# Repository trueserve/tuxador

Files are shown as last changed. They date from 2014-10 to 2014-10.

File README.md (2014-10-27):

# Tuxador

A simple, secure door entry/open counter.

Still in the planning phase.

## Goals

- Make a basic, cost-effective counter
- Use an easy platform (this project will be used to teach)
- Support one doorway and a tamper switch, or two doorways
- Support proper security open/close/tamper/short loop
- Configurable ability to modify or reset the counter
- Indicate power on time, last tamper/short, last open
- All indications on inexpensive LCD display
- Directly mounts to common 16x2 character display or 1.8" Color LCD
- PCB design allows for destroying debugging interfaces
- 4-layer PCB, in cheap fab size, to bury any programming / debugging traces

## What is this useful for?

Some potential uses of this project include:

- Secure doors or closets with internal access logs
- Door entry audible alarm
- Generic upcounter for anything one might use one for

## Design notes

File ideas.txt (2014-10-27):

HW
==
- everything SMD so it can be epoxied or conformal coated easily
- put tamper stickers on external enclosure, probably more important
- ack button? screen light up button? some complex shit?
- ADC read of proper security loop to door contact
  this means: install proper loop resistors at door contact side
- enclosure has a tamper switch?
- internal tamper switch? can code for 2x doors, or 1x door and 1x tamper.
- Built in battery pack / charger? Probably on a separate 2-layer board.

SW
==
- beep/flash when door is opened?
- beeper and lcd backlight are both on external PWM
- LED indicator for something? maybe flash to show the unit is running?
- error display if reset from watchdog reset or BOD? only boot normally from POR?
  this info may be useful: http://www.avrfreaks.net/forum/determining-reset-source-atmega328p
- show state of various things
  - show overall powered uptime
  - show time since last open
  - show time since last tamper/short
  - show state (open/closed/tamper/short)
- Drive digital circuit outputs low to determine if inputs have been damaged
  - only do this occasionally, maybe once every couple of minutes, since it
    looks the same as a short to the system. however doing this is very fast,
    on the order of milliseconds, so it is worthwhile to do

IDEA
====
- maybe the front button can be a status/counter button to flip between the two screens,
  showing the counter normally, or the status

- maybe screen can stay flashing in severe alarm cases (tamper/short) until a timeout or
  cleared by getting into the device or something.

- two unused pins are I2C pins, so if you need I2C shit, those are your free pins.
  otherwise they can be unused, used as GPIO, etc.

====

julian:
you can see why off the shelf units may be ideal - less shit to think about, less code to write :)
if your time is worth nothing (or if you enjoy doing this / learning) then this will be cheaper,
otherwise it can be quite a bit more expensive

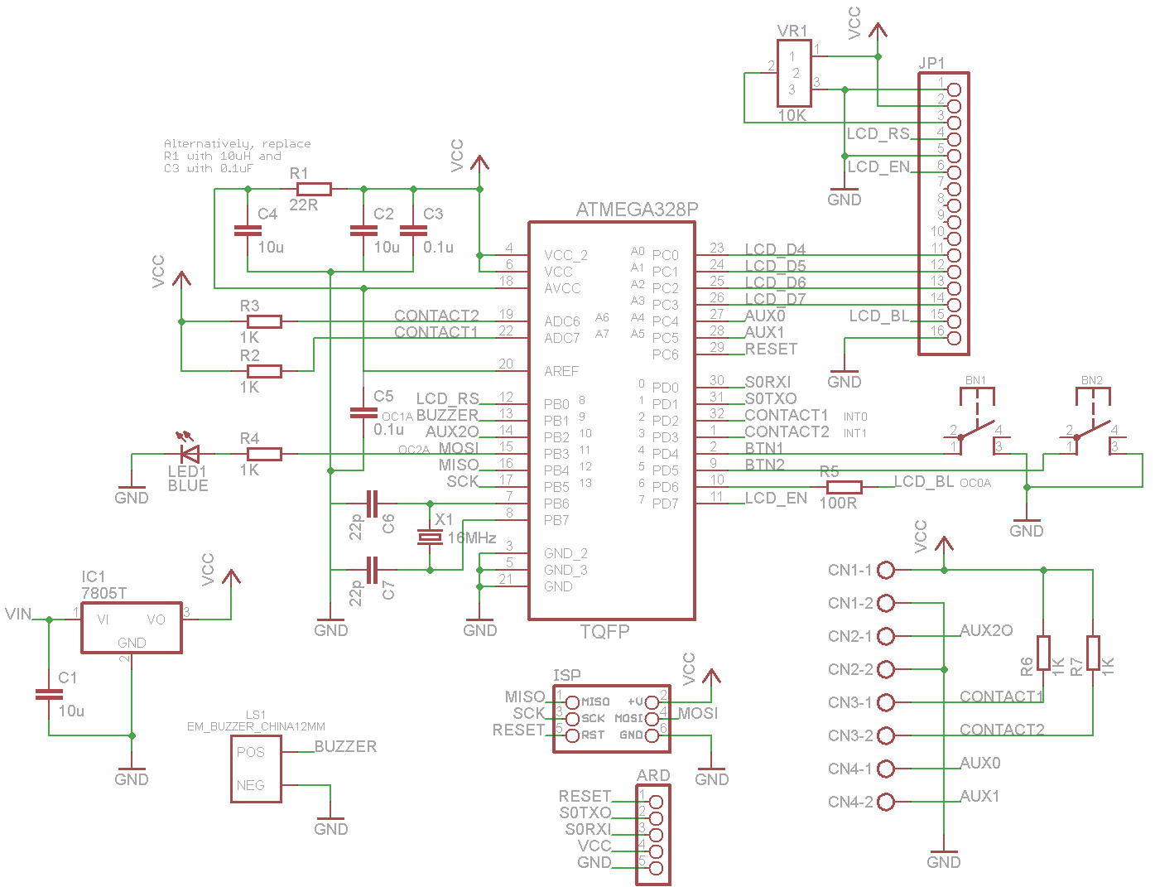
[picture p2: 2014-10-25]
misc/Tuxador_r1_sch_20141025.png

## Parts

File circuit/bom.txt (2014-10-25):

Prices are Qty 1 / Qty 10 for all count

1x 3.50/3.50 PCB
             Cost to manufacture ~$35 per 10 boards

1x 2.60/2.60 White-on-Blue 1602 LCD display
             ebay "1602 lcd" - lots of choices and price ranges, just need basic 5V version

1x 3.43/3.02 ATMega328P-AU or ATMega168PA-AU
             http://www.mouser.com/ProductDetail/Atmel/ATMEGA328P-AU/?qs=sGAEpiMZZMtVoztFdqDXO3RbBx7FKCmV
             I might have one on hand; not sure. 

1x 5.40/4.80 Hammond 1591ATBU case
             http://www.mouser.com/ProductDetail/Hammond-Manufacturing/1591ATBU/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

4x 2.00/0.35 Low-cost 5.08mm terminal connectors
             ebay "5.08mm terminal blue" as cheap as 10c each, usually packs of 20 or 100
             I have these on hand

1x ?.??/?.?? 6x6x6 4pin tact switch
             ebay "6x6 tact" - get whatever is cheapest. used for internal button
             I have these on hand

1x ?.??/?.?? 6x6x20mm 4pin tact switch
             ebay "6x6x20 tact" - used for front indicator button
             I have some ordered and coming in.

1x ?.??/?.?? tact button cap
             ebay "tact button cap round" - whatever style you want, for round buttons, should work OK
             they are hard to find, but I am sure we could mod the square ones to work - ignore for now

Totals
Qty 1:  $16.93
Qty 10: $14.27

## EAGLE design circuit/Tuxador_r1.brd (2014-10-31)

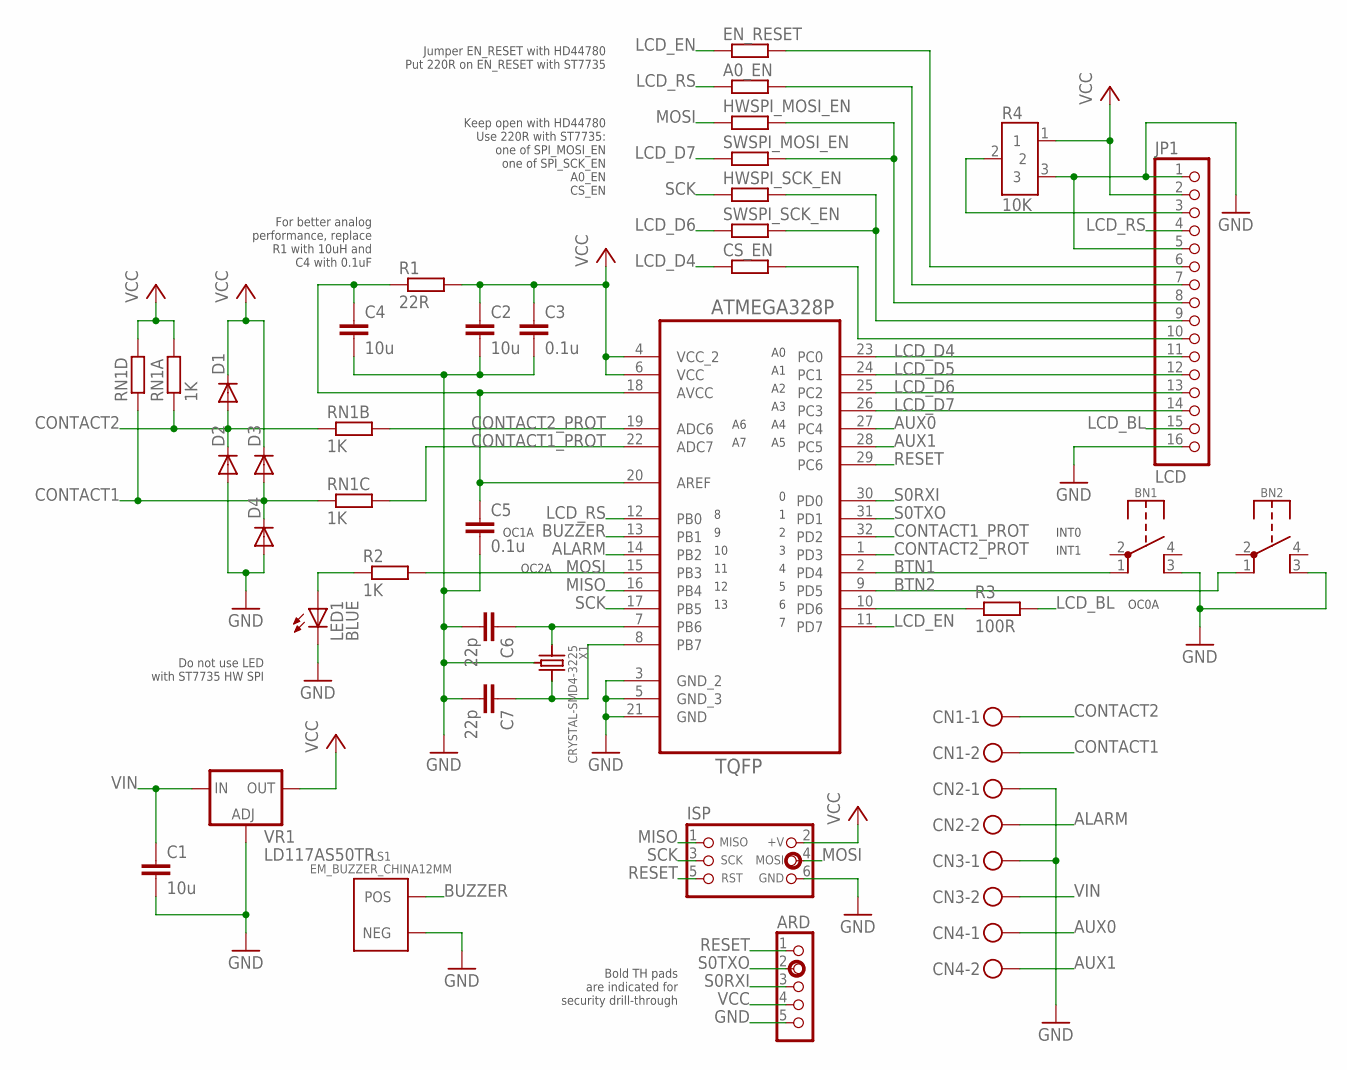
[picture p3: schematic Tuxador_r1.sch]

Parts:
A0_EN: -0-; R1206
ARD: CON_HEADER_1X05-PTH; M1X5
BN1, BN2: SCHURTER_PUSHBTN_LPH; SCHURTER_LPH
C1, C2, C4: 10u; C0805
C3, C5: 0.1u; C0805
C6, C7: 22p; C0603
CN1, CN2, CN3, CN4: MKDSN1,5/2-5,08
CS_EN: -0-; R1206
D1, D2, D3, D4: DIODE-SOT23; SOT-23
EN_RESET: -0-; R1206
HWSPI_MOSI_EN: -0-; R1206
HWSPI_SCK_EN: -0-; R1206
ISP: CON_HEADER_PRG_AVR_ICSP_NOLBL; HEADER_PRG_2X03_NOLBL
JP1: LCD; 1X16
LED1: BLUE; LED-3MM
LS1: EM_BUZZER_CHINA12MM; CHINA_ELECTRO_SOUNDER_12MM
R1: 22R; R1206
R2: 1K; R1206
R3: 100R; R1206
R4: 10K; BI-TECH_36P-POT
RN1: 1K; RN8P-4R-CRA06S
SWSPI_MOSI_EN: -0-; R1206
SWSPI_SCK_EN: -0-; R1206
U1: ATMEGA328P-AU; QFP80P900X900X120-32N
VR1: LD117AS50TR; SOT223
X1: CRYSTAL-SMD4-3225; 3.2X2.5MM

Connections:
ALARM: CN2.2, U1.14 (PB2)
AUX0: CN4.1, U1.27 (PC4)
AUX1: CN4.2, U1.28 (PC5)
AVCC: C4.1, C5.1, R1.1, U1.18 (AVCC), U1.20 (AREF)
BTN1: BN1.1, U1.2 (PD4)
BTN2: BN2.1, U1.9 (PD5)
BUZZER: LS1.POS, U1.13 (PB1)
CONTACT1: CN1.2, D3.1 (A), D4.3 (C), RN1.3 (1), RN1.4 (1)
CONTACT1_PROT: RN1.6 (2), U1.22 (ADC7), U1.32 (PD2)
CONTACT2: CN1.1, D1.1 (A), D2.3 (C), RN1.1, RN1.2 (1)
CONTACT2_PROT: RN1.7 (2), U1.1 (PD3), U1.19 (ADC6)
GND: ARD.5, BN1.3, BN2.3, C1.2, C2.2, C3.2, C4.2, C5.2, C6.2, C7.2, CN2.1, CN3.1, D2.1 (A), D4.1 (A), ISP.6 (GND), JP1.1, JP1.5, JP1.16, LED1.K (C), LS1.NEG, R4.3, U1.3 (GND_2), U1.5 (GND_3), U1.21 (GND), VR1.1 (ADJ), X1.2 (GND), X1.4 (GND)
LCD_BL: JP1.15, R3.2
LCD_BL_MCU: R3.1, U1.10 (PD6)
LCD_D4: CS_EN.1, JP1.11, U1.23 (PC0)
LCD_D5: JP1.12, U1.24 (PC1)
LCD_D6: JP1.13, SWSPI_SCK_EN.1, U1.25 (PC2)
LCD_D7: JP1.14, SWSPI_MOSI_EN.1, U1.26 (PC3)
LCD_EN: EN_RESET.1, U1.11 (PD7)
LCD_EN_RESET: EN_RESET.2, JP1.6
LCD_RS: A0_EN.1, JP1.4, U1.12 (PB0)
MISO: ISP.1 (MISO), U1.16 (PB4)
MOSI: HWSPI_MOSI_EN.1, ISP.4 (MOSI), R2.2, U1.15 (PB3)
unnamed: LED1.A, R2.1
unnamed: JP1.3, R4.2
unnamed: A0_EN.2, JP1.7
unnamed: HWSPI_MOSI_EN.2, JP1.8, SWSPI_MOSI_EN.2
unnamed: HWSPI_SCK_EN.2, JP1.9, SWSPI_SCK_EN.2
unnamed: CS_EN.2, JP1.10
OSC1: C6.1, U1.7 (PB6), X1.1
OSC2: C7.1, U1.8 (PB7), X1.3 (2)
RESET: ARD.1, ISP.5 (RST), U1.29 (PC6)
S0RXI: ARD.3, U1.30 (PD0)
S0TXO: ARD.2, U1.31 (PD1)
SCK: HWSPI_SCK_EN.1, ISP.3 (SCK), U1.17 (PB5)
VCC: ARD.4, C2.1, C3.1, D1.3 (C), D3.3 (C), ISP.2 (+V), JP1.2, R1.2, R4.1, RN1.5 (2), RN1.8 (2), U1.4 (VCC_2), U1.6 (VCC), VR1.4 (OUT)
VIN: C1.1, CN3.2, VR1.3 (IN)

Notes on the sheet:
For better analog performance, replace R1 with 10uH and C4 with 0.1uF
OC0A
OC1A
INT0
INT1
OC2A
Jumper EN_RESET with HD44780 Put 220R on EN_RESET with ST7735
Keep open with HD44780 Use 220R with ST7735: one of SPI_MOSI_EN one of SPI_SCK_EN A0_EN CS_EN
Do not use LED with ST7735 HW SPI
Bold TH pads are indicated for security drill-through

Board: 2 copper layers, 37 parts (15 on the bottom side), 37 nets, no tracks yet.

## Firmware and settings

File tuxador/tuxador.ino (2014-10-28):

/*
 * Tuxador
 * a simple door counter device
 *
 * circuit and code Copyright 2014 true <trueamx at gmail dot com>
 * original idea and code Copyright 2014 tuxavant <tuxavant at tuxavant dot com>
 *
 */

#include "tuxador.h"

/*******************************************/
/* -- CONFIGURATION ---------------------- */
// see tuxador.h for configuration defines.

#define LCD_TYPE             LCD_HD44780     // LCD_HD44780, LCD_ST7735_HW/SW


/*******************************************/
/* -- GLOBAL ----------------------------- */
uint8_t brightness;


/*******************************************/
/* -- STARTUP ---------------------------- */
void setup()
{
  
}


/* -- MAINLINE --------------------------- */
void loop()
{
  
}

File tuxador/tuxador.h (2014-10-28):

/*
 * Tuxador
 * a simple door counter device
 *
 * circuit and code Copyright 2014 true <trueamx at gmail dot com>
 * original idea and code Copyright 2014 tuxavant <tuxavant at tuxavant dot com>
 *
 */

#include <stdint.h>

#include <avr/interrupt.h>
#include <avr/eeprom.h>
#include <avr/sleep.h>


/* -- LCD COMMON ------------------------- */
#define LCD_HD44780          0  // 16x2 character LCD
#define LCD_ST7735_HW        1  // typically 1.8" 128x160 TFT LCD using HW SPI
#define LCD_ST7735_SW        2  // above, but using soft SPI
                                // The original circuit uses hard SPI because only MOSI is used
                                // Also, the LED will NOT be used in hard SPI mode,
                                // instead any indicators will be on-screen.
#define LCD_BACKLIGHT        6  // pin 6 = brightness control. other pins on/off only


/* -- HD44780 CONFIG --------------------- */
#define LCD_HD44780_D4       A0 // HD44780 pin 11-14, must be on the same port, ascending
#define LCD_HD44780_EN       7  // HD44780 pin 6
#define LCD_HD44780_RS       8  // HD44780 pin 4
 
 
/* -- ST7735 CONFIG ---------------------- */
#define LCD_ST7735_RESET     7  // HD44780 pin 6
#define LCD_ST7735_A0        8  // HD44780 pin 7, jumpered
#define LCD_ST7735_SW_MOSI   A3 // HD44780 pin 8, jumpered
#define LCD_ST7735_SW_SCK    A2 // HD44780 pin 9, jumpered
#define LCD_ST7735_CS        A0 // HD44780 pin 10, jumpered

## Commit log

2014-10-25 Initial schematic
    This is the initial schematic for the door counter project.
    Also have an incomplete BOM and some implementation ideas.
    Decided on possible Arduino compatibility not because it is best for the
    job, but because it is barely capable and others know how to work on it.
    BOM is probably $2 higher and programming will probably be buggier an
    take longer because of this. Still have time to determine if this should
    be standard C or if the micro should be changed altogether.
    Likewise, chose Eagle for CAD as many are familiar with it, and I don't
    care for KiCad. (Don't care for Eagle much either, but...)
    [Tuxador_r1.sch]
2014-10-25 Remove redundant pull-up resistors
    Removed redundant R6 and R7 contact pull-up resistors
    [Tuxador_r1.sch]
2014-10-26 Reorganized files
    - Renamed pcb/ to circuit/
    - Moved ideas.txt to root
    [Tuxador_r1.sch]
2014-10-26 Added .gitignore
    Ignoring Eagle automatic backups of schematics, boards and libraries
2014-10-27 Add clamping diodes
    Clamping diodes have been added to the contact inputs.
    Support for ST7735-compatible LCDs has been added to the main LCD
    header.
    [Tuxador_r1.sch]
2014-10-27 Initial code added
    Absolutely nothing here yet, but setting up the layout / formatting and
    some pin defines for the LCD interface.
2014-10-27 Minor schematic updates
    - Cleaned up some sections
    - Added more descriptive text
    - Indicated drill-through holes for security on programming headers.
    These will be located on their own section on the board but depending on
    board costs to mill these sections I want to indicate where a drill can
    be used.
    - Added a series resistor for the A0 line if using ST7735 LCD, otherwise
    it won't work :)
    [Tuxador_r1.sch]
2014-10-29 Added resistors for clamping diode protection
    Oops
    [Tuxador_r1.sch]
2014-10-31 Component update; initial board layout
    Components have been updated as necessary for the design. Examples are
    changing the voltage regulator and the crystal.
    Initial board component placement. Still a lot of work to do here before
    running traces.
    [Tuxador_r1.brd, Tuxador_r1.sch]
